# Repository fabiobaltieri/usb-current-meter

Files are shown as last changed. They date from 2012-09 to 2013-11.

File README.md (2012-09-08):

USB Current Meter
=================

This is a set of projects used to monitor the power used in an electrical
system using split core current sensors.

Project page on:

http://fabiobaltieri.com/2012/08/09/usb-current-meter/

License
-------

This program is free software: you can redistribute it and/or modify
it under the terms of the GNU General Public License as published by
the Free Software Foundation, either version 2 of the License, or
(at your option) any later version.

Contents
--------

    COPYING        text version of the GPL
    README         this file
    bootloader-8x/ source directory for 8x version bootloader
    commandline/   source directory for the commandline utility
    firmware*/     source directory for firmware files
    hardware/      source directory for the hardware design files
    rrd/           script and examples for usage with rrdtool

Firmware
--------

Building requires an avr-gcc toolchain, in the firmware/ directory, to build
run:

    make main.hex

Flashing the firmware on the device requires avrdude and a compatible hardware
programmer. Default configuration is stored at the beginning of the Makefile.
To program with the default configuration, run:

    make flash

Fuses can be configured running:

    make fuses

Hardware
--------

All hardware files (schematic, layout and libraries) are in CadSoft Eagle 6
format.

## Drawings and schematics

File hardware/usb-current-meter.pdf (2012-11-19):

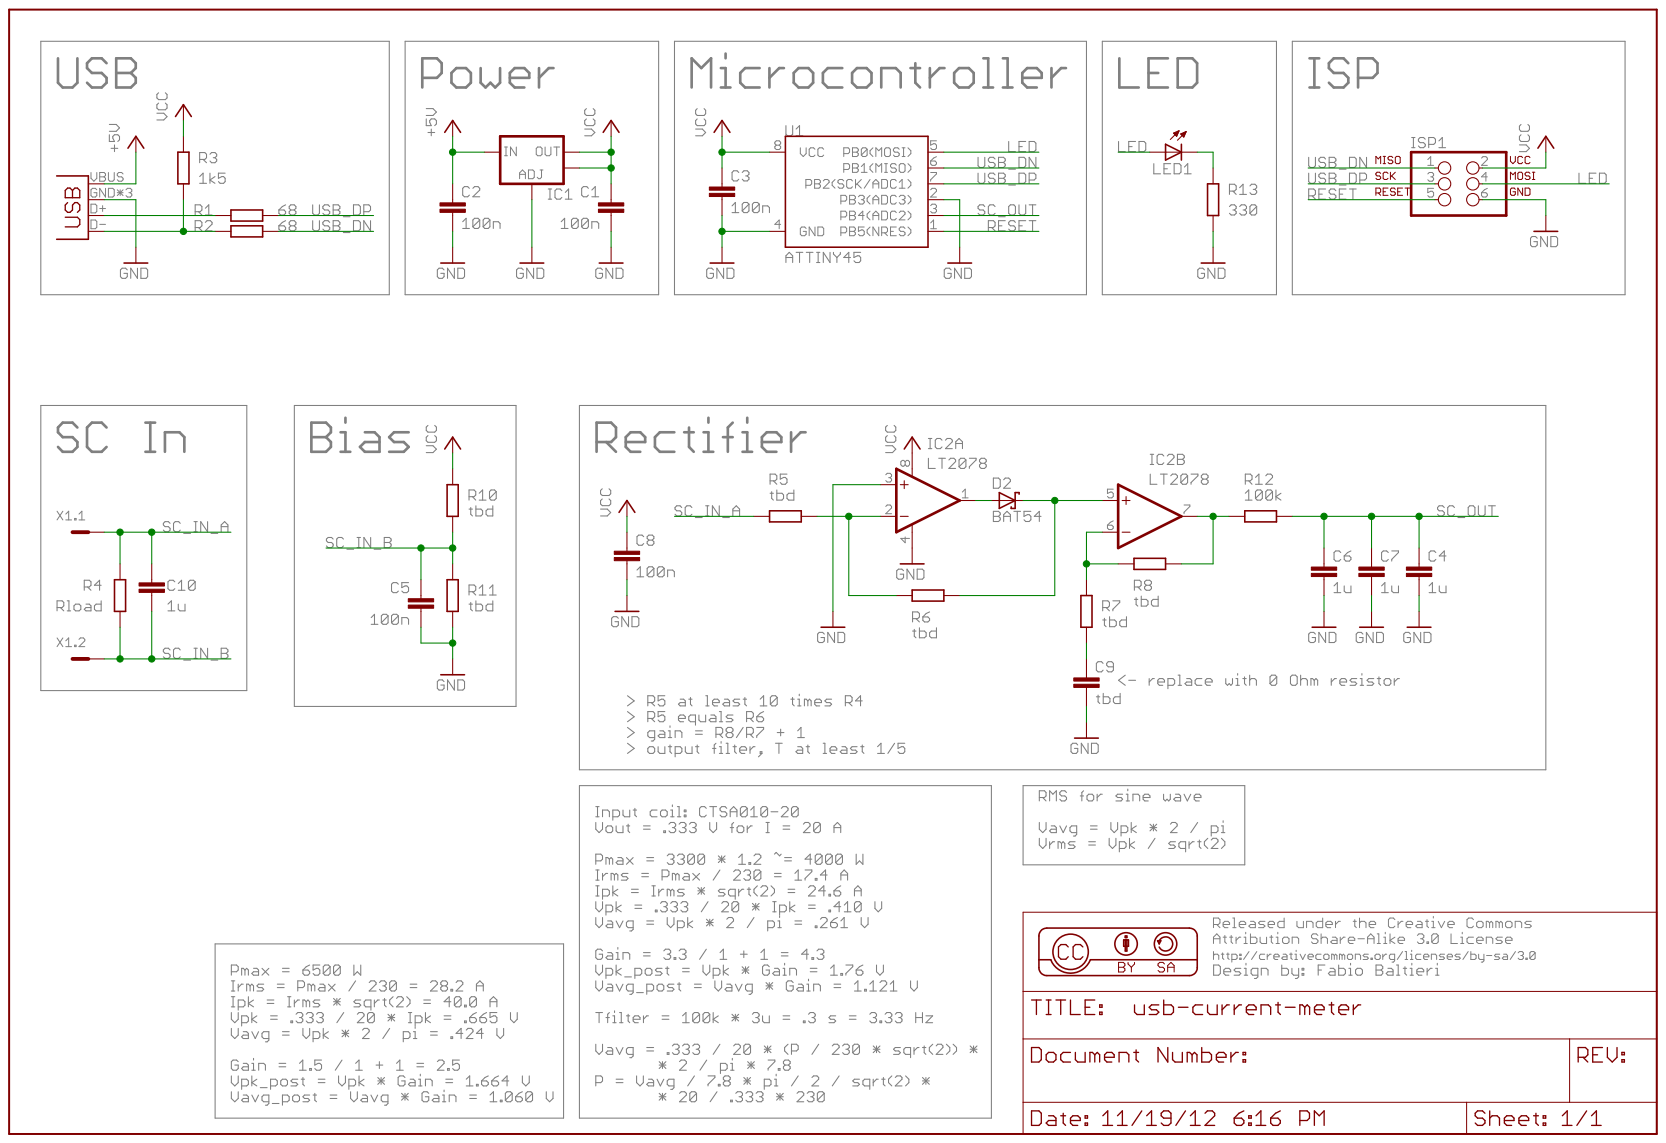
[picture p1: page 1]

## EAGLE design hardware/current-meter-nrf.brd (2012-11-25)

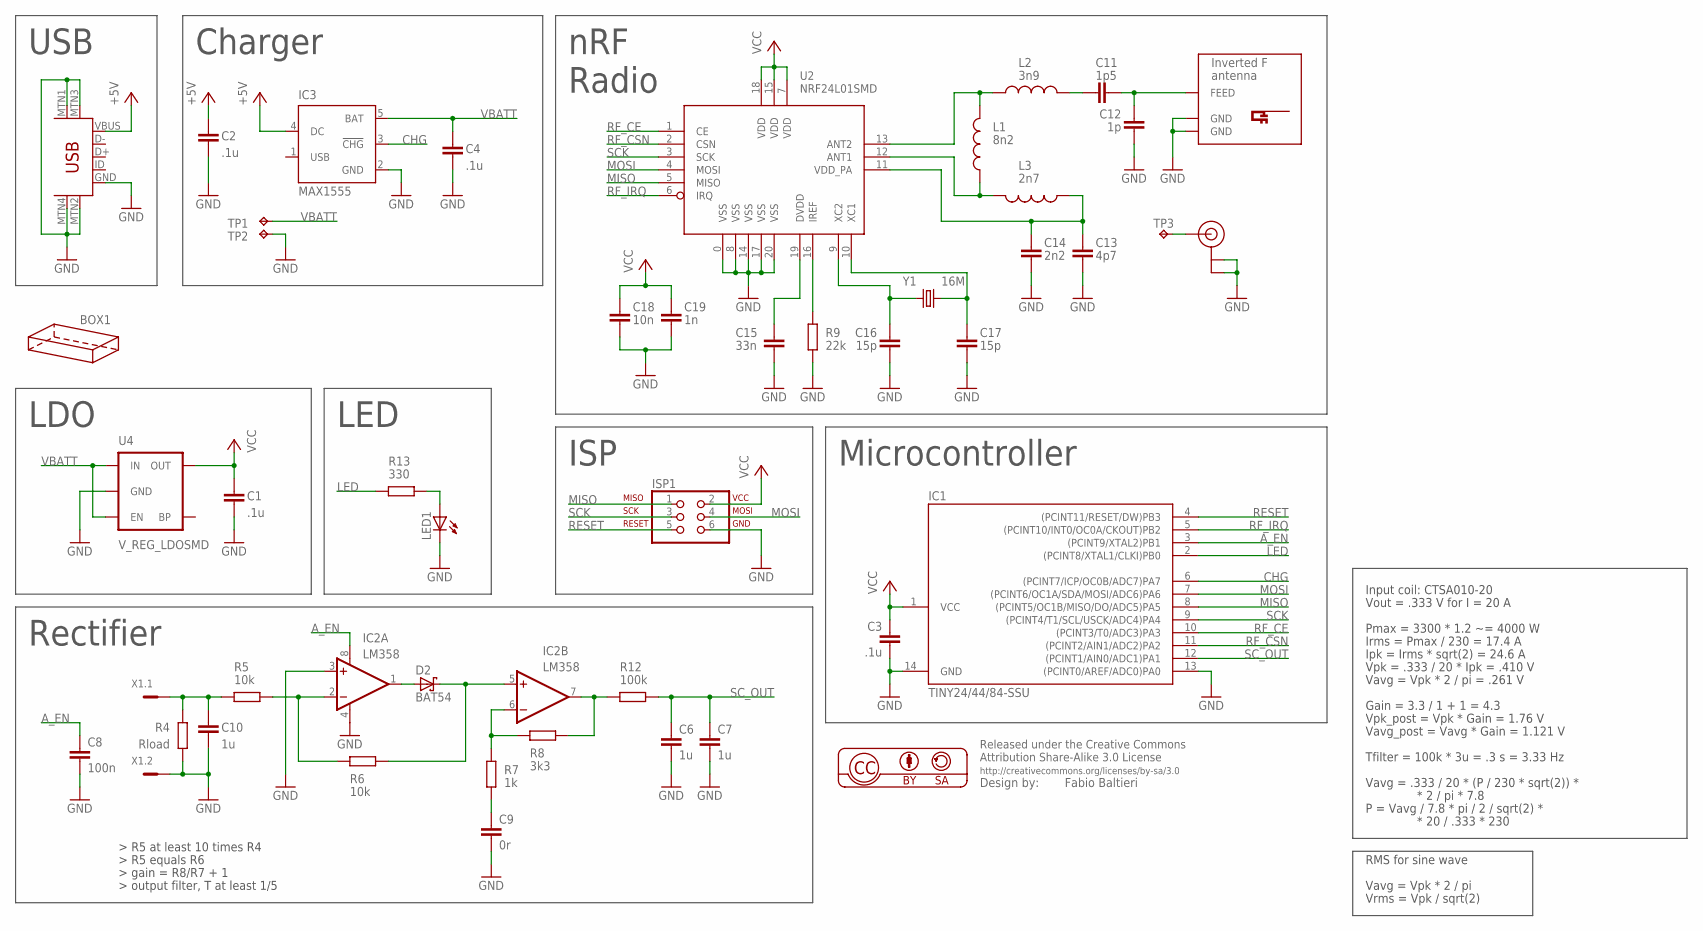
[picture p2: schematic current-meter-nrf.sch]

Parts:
BOX1: HAMMOND-BOX-G-1H; 1551G-1HOLE
C1, C2, C3, C4: .1u; C0805
C6, C7, C10: 1u; C0805
C8: 100n; C0805
C9: 0r; C0805
C11: 1p5; C0603
C12: 1p; C0603
C13: 4p7; C0603
C14: 2n2; C0603
C15: 33n; C0603
C16, C17: 15p; C0603
C18: 10n; C0603
C19: 1n; C0603
D2: BAT54; SOT23
IC1: TINY24/44/84-SSU; SOIC14
IC2: LM358; SO08
IC3: MAX1555; SOT23-5L
ISP1: ISP-AVR910PTH; 2X03
L1: 8n2; 0603
L2: 3n9; 0603
L3: 2n7; 0603
LED1: LEDSML0805; SML0805
R4: Rload; R0805
R5, R6: 10k; R0603
R7: 1k; R0603
R8: 3k3; R0603
R9: 22k; R0603
R12: 100k; R0603
R13: 330; R0603
TP1, TP2: TPTP12R; TP12R
TP3: TPTP08SQ; TP08SQ
U2: NRF24L01SMD; QFN20
U3: USB-MINIB-5PIN; USB-MINIB
U4: V_REG_LDOSMD; SOT23-5
U$1: INVERTED_F_ANTENNA+5; DN007+5
U$2: U.FL
X1: MC2
Y1: 16M; CRYSTAL-SMD-5X3

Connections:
+5V: C2.1, IC3.4 (DC), U3.VBUS
A_EN: C8.1, IC1.3 ((PCINT9/XTAL2)PB1), IC2.8 (V+)
CHG: IC1.6 ((PCINT7/ICP/OC0B/ADC7)PA7), IC3.3 (!CHG)
GND: C1.2, C2.2, C3.2, C4.2, C6.2, C7.2, C8.2, C9.2, C10.2, C12.2, C13.2, C14.2, C15.2, C16.2, C17.2, C18.2, C19.2, IC1.13 ((PCINT0/AREF/ADC0)PA0), IC1.14 (GND), IC2.3 (+IN), IC2.4 (V-), IC3.2 (GND), ISP1.6, LED1.C, R4.1, R9.2, TP2.TP, U2.0 (VSS), U2.8 (VSS), U2.14 (VSS), U2.17 (VSS), U2.20 (VSS), U3.GND, U3.MTN1 (MTN2), U3.MTN2 (MTN3), U3.MTN3 (MTN1), U3.MTN4, U4.2 (GND), U$1.GND, U$1.GND@1 (GND), U$2.P$1 (GND), U$2.P$2 (GND), X1.2
LED: IC1.2 ((PCINT8/XTAL1/CLKI)PB0), R13.2
MISO: IC1.8 ((PCINT5/OC1B/MISO/DO/ADC5)PA5), ISP1.1, U2.5 (MISO)
MOSI: IC1.7 ((PCINT6/OC1A/SDA/MOSI/ADC6)PA6), ISP1.4, U2.4 (MOSI)
unnamed: LED1.A, R13.1
unnamed: C9.1, R7.1
unnamed: L1.2, L3.2, U2.12 (ANT1)
unnamed: L1.1, L2.1, U2.13 (ANT2)
unnamed: IC2.2 (-IN), R5.2, R6.1
unnamed: D2.1 (A), IC2.1 (OUT)
unnamed: D2.3 (C), IC2.5 (+IN), R6.2
unnamed: C11.1, L2.2
unnamed: IC2.6 (-IN), R7.2, R8.1
unnamed: IC2.7 (OUT), R8.2, R12.1
unnamed: C11.2, C12.1, U$1.FEED
unnamed: C13.1, C14.1, L3.1, U2.11 (VDD_PA)
unnamed: C15.1, U2.19 (DVDD)
unnamed: R9.1, U2.16 (IREF)
unnamed: C17.1, U2.10 (XC1), Y1.3 (2)
unnamed: C16.1, U2.9 (XC2), Y1.1
unnamed: TP3.TP, U$2.P$3 (SIGNAL)
RESET: IC1.4 ((PCINT11/RESET/DW)PB3), ISP1.5
RF_CE: IC1.10 ((PCINT3/T0/ADC3)PA3), U2.1 (CE)
RF_CSN: IC1.11 ((PCINT2/AIN1/ADC2)PA2), U2.2 (CSN)
RF_IRQ: IC1.5 ((PCINT10/INT0/OC0A/CKOUT)PB2), U2.6 (IRQ)
SCK: IC1.9 ((PCINT4/T1/SCL/USCK/ADC4)PA4), ISP1.3, U2.3 (SCK)
SC_IN_A: C10.1, R4.2, R5.1, X1.1
SC_OUT: C6.1, C7.1, IC1.12 ((PCINT1/AIN0/ADC1)PA1), R12.2
VBATT: C4.1, IC3.5 (BAT), TP1.TP, U4.1 (IN), U4.3 (EN)
VCC: C1.1, C3.1, C18.1, C19.1, IC1.1 (VCC), ISP1.2, U2.7 (VDD), U2.15 (VDD), U2.18 (VDD), U4.5 (OUT)

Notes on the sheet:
USB
Microcontroller
ISP
LED
Rectifier
Pmax = 3300 * 1.2 ~= 4000 W
Irms = Pmax / 230 = 17.4 A
Ipk = Irms * sqrt(2) = 24.6 A
Vpk = .333 / 20 * Ipk = .410 V
Vout = .333 V for I = 20 A
Input coil: CTSA010-20
Vavg = Vpk * 2 / pi = .261 V
Gain = 3.3 / 1 + 1 = 4.3
Vpk_post = Vpk * Gain = 1.76 V
Vavg_post = Vavg * Gain = 1.121 V
RMS for sine wave
Vavg = Vpk * 2 / pi
Vrms = Vpk / sqrt(2)
Tfilter = 100k * 3u = .3 s = 3.33 Hz
Vavg = .333 / 20 * (P / 230 * sqrt(2)) *
* 2 / pi * 7.8
P = Vavg / 7.8 * pi / 2 / sqrt(2) *
* 20 / .333 * 230
nRF
Charger
Radio
LDO

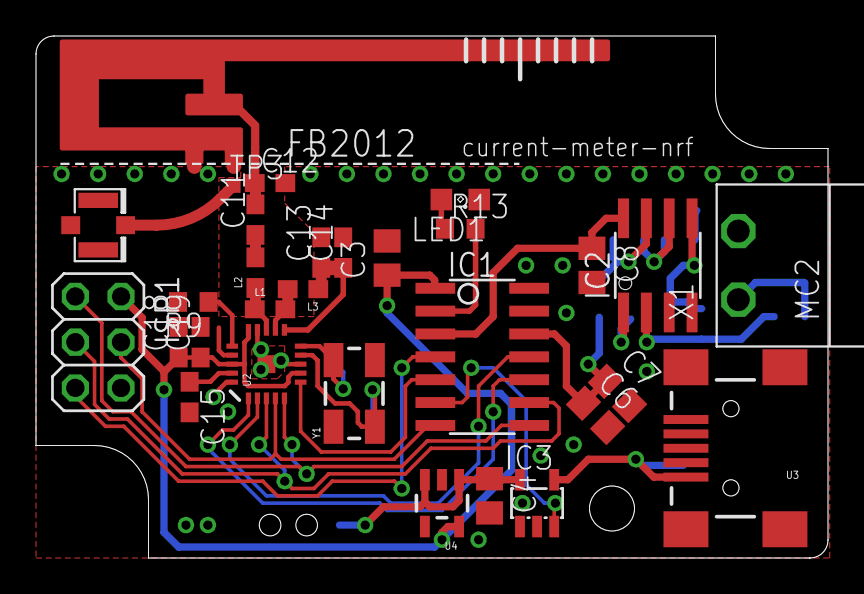
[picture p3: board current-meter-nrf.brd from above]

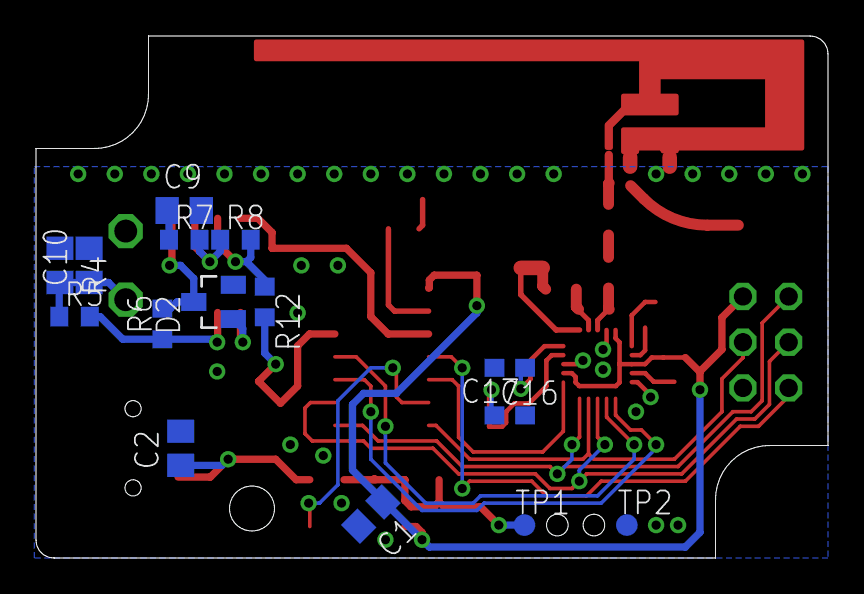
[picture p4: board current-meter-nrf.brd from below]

Board: 2 copper layers, 44.0 x 29.0 mm, 46 parts (15 on the bottom side), 33 nets.

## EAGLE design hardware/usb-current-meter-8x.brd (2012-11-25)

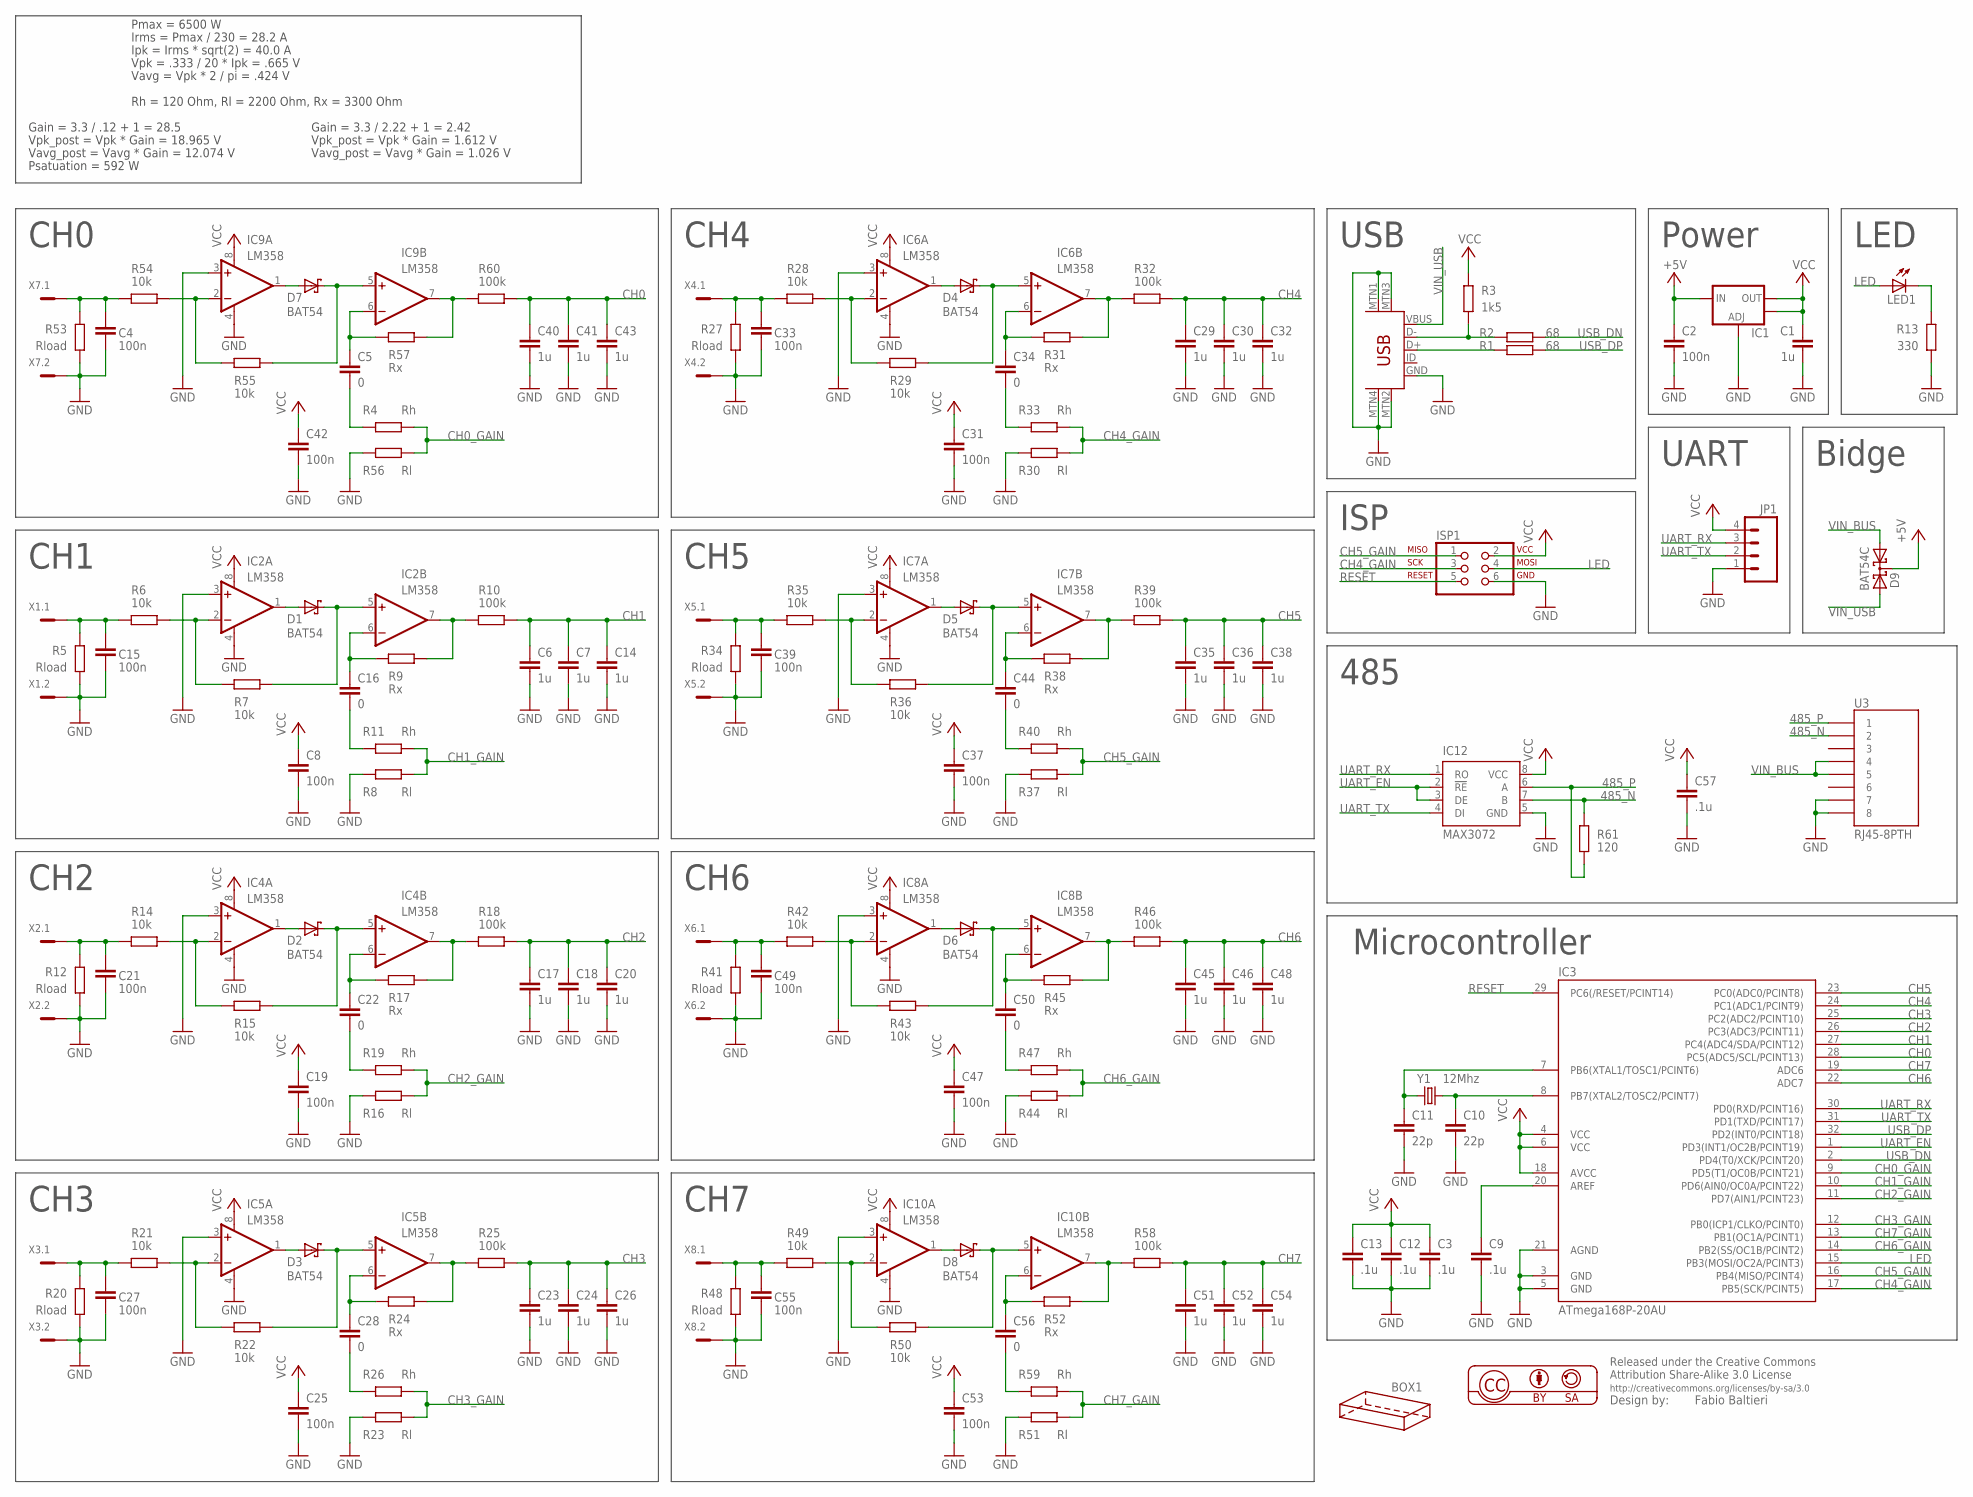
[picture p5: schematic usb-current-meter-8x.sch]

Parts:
BOX1: HAMMOND-BOX-XXA; 1591XXA
C1, C6, C7, C14, C17, C18, C20, C23, C24, C26, C29, C30, C32, C35, C36, C38, C40, C41, C43, C45, C46, C48, C51, C52, C54: 1u; C0805
C2, C4, C8, C15, C19, C21, C25, C27, C31, C33, C37, C39, C42, C47, C49, C53, C55: 100n; C0805
C3, C9, C12, C13, C57: .1u; C0805
C5, C16, C22, C28, C34, C44, C50, C56: 0; C0805
C10, C11: 22p; C0805
D1, D2, D3, D4, D5, D6, D7, D8: BAT54; SOT23
D9: BAT54C; SOT23
IC1: V_REG_LM1117SOT223; SOT223
IC2, IC4, IC5, IC6, IC7, IC8, IC9, IC10: LM358; SO08
IC3: ATmega168P-20AU; TQFP32-08
IC12: MAX3072; SOIC8
ISP1: ISP-AVR910PTH; 2X03
JP1: M04PTH; 1X04
LED1: LEDSML0805; SML0805
R1, R2: 68; R0603
R3: 1k5; R0603
R4, R11, R19, R26, R33, R40, R47, R59: Rh; R0603
R5, R12, R20, R27, R34, R41, R48, R53: Rload; R0805
R6, R7, R14, R15, R21, R22, R28, R29, R35, R36, R42, R43, R49, R50, R54, R55: 10k; R0603
R8, R16, R23, R30, R37, R44, R51, R56: Rl; R0603
R9, R17, R24, R31, R38, R45, R52, R57: Rx; R0603
R10, R18, R25, R32, R39, R46, R58, R60: 100k; R0603
R13: 330; R0603
R61: 120; R0603
U3: RJ45-8PTH; RJ45-8
U$1: USB-MINIB-5PIN; USB-MINIB
U$2: Fabio Baltieri; CREATIVE_COMMONS
X1, X2, X3, X4, X5, X6, X7, X8: MC2
Y1: 12Mhz; HC49U-V

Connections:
485_N: IC12.7 (B), R61.1, U3.2
485_P: IC12.6 (A), R61.2, U3.1
+5V: C2.1, D9.3 (CC), IC1.3 (IN)
CH0: C40.1, C41.1, C43.1, IC3.28 (PC5(ADC5/SCL/PCINT13)), R60.2
CH0_GAIN: IC3.9 (PD5(T1/OC0B/PCINT21)), R4.1, R56.2
CH0_IN: C4.1, R53.2, R54.1, X7.1
CH0_IN1: C15.1, R5.2, R6.1, X1.1
CH0_IN2: C21.1, R12.2, R14.1, X2.1
CH0_IN3: C33.1, R27.2, R28.1, X4.1
CH0_IN4: C39.1, R34.2, R35.1, X5.1
CH0_IN5: C55.1, R48.2, R49.1, X8.1
CH0_IN6: C27.1, R20.2, R21.1, X3.1
CH0_IN8: C49.1, R41.2, R42.1, X6.1
CH1: C6.1, C7.1, C14.1, IC3.27 (PC4(ADC4/SDA/PCINT12)), R10.2
CH1_GAIN: IC3.10 (PD6(AIN0/OC0A/PCINT22)), R8.2, R11.1
CH2: C17.1, C18.1, C20.1, IC3.26 (PC3(ADC3/PCINT11)), R18.2
CH2_GAIN: IC3.11 (PD7(AIN1/PCINT23)), R16.2, R19.1
CH3: C23.1, C24.1, C26.1, IC3.25 (PC2(ADC2/PCINT10)), R25.2
CH3_GAIN: IC3.12 (PB0(ICP1/CLKO/PCINT0)), R23.2, R26.1
CH4: C29.1, C30.1, C32.1, IC3.24 (PC1(ADC1/PCINT9)), R32.2
CH4_GAIN: IC3.17 (PB5(SCK/PCINT5)), ISP1.3, R30.2, R33.1
CH5: C35.1, C36.1, C38.1, IC3.23 (PC0(ADC0/PCINT8)), R39.2
CH5_GAIN: IC3.16 (PB4(MISO/PCINT4)), ISP1.1, R37.2, R40.1
CH6: C45.1, C46.1, C48.1, IC3.22 (ADC7), R46.2
CH6_GAIN: IC3.14 (PB2(SS/OC1B/PCINT2)), R44.2, R47.1
CH7: C51.1, C52.1, C54.1, IC3.19 (ADC6), R58.2
CH7_GAIN: IC3.13 (PB1(OC1A/PCINT1)), R51.2, R59.1
GND: C1.2, C2.2, C3.2, C4.2, C6.2, C7.2, C8.2, C9.2, C10.2, C11.2, C12.2, C13.2, C14.2, C15.2, C17.2, C18.2, C19.2, C20.2, C21.2, C23.2, C24.2, C25.2, C26.2, C27.2, C29.2, C30.2, C31.2, C32.2, C33.2, C35.2, C36.2, C37.2, C38.2, C39.2, C40.2, C41.2, C42.2, C43.2, C45.2, C46.2, C47.2, C48.2, C49.2, C51.2, C52.2, C53.2, C54.2, C55.2, C57.2, IC1.1 (ADJ), IC2.3 (+IN), IC2.4 (V-), IC3.3 (GND), IC3.5 (GND), IC3.21 (AGND), IC4.3 (+IN), IC4.4 (V-), IC5.3 (+IN), IC5.4 (V-), IC6.3 (+IN), IC6.4 (V-), IC7.3 (+IN), IC7.4 (V-), IC8.3 (+IN), IC8.4 (V-), IC9.3 (+IN), IC9.4 (V-), IC10.3 (+IN), IC10.4 (V-), IC12.5 (GND), ISP1.6, JP1.1, R5.1, R8.1, R12.1, R13.1, R16.1, R20.1, R23.1, R27.1, R30.1, R34.1, R37.1, R41.1, R44.1, R48.1, R51.1, R53.1, R56.1, U3.7, U3.8, U$1.GND, U$1.MTN1 (MTN2), U$1.MTN2 (MTN3), U$1.MTN3 (MTN1), U$1.MTN4, X1.2, X2.2, X3.2, X4.2, X5.2, X6.2, X7.2, X8.2
LED: IC3.15 (PB3(MOSI/OC2A/PCINT3)), ISP1.4, LED1.A
unnamed: R2.1, R3.1, U$1.D-
unnamed: R1.1, U$1.D+
unnamed: LED1.C, R13.2
unnamed: C11.1, IC3.7 (PB6(XTAL1/TOSC1/PCINT6)), Y1.1
unnamed: C10.1, IC3.8 (PB7(XTAL2/TOSC2/PCINT7)), Y1.2
unnamed: C9.1, IC3.20 (AREF)
unnamed: C5.2, R4.2
unnamed: IC2.2 (-IN), R6.2, R7.1
unnamed: D1.1 (A), IC2.1 (OUT)
unnamed: D1.3 (C), IC2.5 (+IN), R7.2
unnamed: C16.1, IC2.6 (-IN), R9.1
unnamed: IC2.7 (OUT), R9.2, R10.1
unnamed: C16.2, R11.2
unnamed: IC4.2 (-IN), R14.2, R15.1
unnamed: D2.1 (A), IC4.1 (OUT)
unnamed: D2.3 (C), IC4.5 (+IN), R15.2
unnamed: C22.1, IC4.6 (-IN), R17.1
unnamed: IC4.7 (OUT), R17.2, R18.1
unnamed: C22.2, R19.2
unnamed: IC6.2 (-IN), R28.2, R29.1
unnamed: D4.1 (A), IC6.1 (OUT)
unnamed: D4.3 (C), IC6.5 (+IN), R29.2
unnamed: C34.1, IC6.6 (-IN), R31.1
unnamed: IC6.7 (OUT), R31.2, R32.1
unnamed: C34.2, R33.2
unnamed: IC7.2 (-IN), R35.2, R36.1
unnamed: D5.1 (A), IC7.1 (OUT)
unnamed: D5.3 (C), IC7.5 (+IN), R36.2
unnamed: C44.1, IC7.6 (-IN), R38.1
unnamed: IC7.7 (OUT), R38.2, R39.1
unnamed: C44.2, R40.2
unnamed: IC10.2 (-IN), R49.2, R50.1
unnamed: D8.1 (A), IC10.1 (OUT)
unnamed: D8.3 (C), IC10.5 (+IN), R50.2
unnamed: C56.1, IC10.6 (-IN), R52.1
unnamed: IC10.7 (OUT), R52.2, R58.1
unnamed: IC9.2 (-IN), R54.2, R55.1
unnamed: D7.1 (A), IC9.1 (OUT)
unnamed: D7.3 (C), IC9.5 (+IN), R55.2
unnamed: C5.1, IC9.6 (-IN), R57.1
unnamed: IC9.7 (OUT), R57.2, R60.1
unnamed: C56.2, R59.2
unnamed: IC5.2 (-IN), R21.2, R22.1
unnamed: D3.1 (A), IC5.1 (OUT)
unnamed: D3.3 (C), IC5.5 (+IN), R22.2
unnamed: C28.1, IC5.6 (-IN), R24.1
unnamed: IC5.7 (OUT), R24.2, R25.1
unnamed: C28.2, R26.2
unnamed: IC8.2 (-IN), R42.2, R43.1
unnamed: D6.1 (A), IC8.1 (OUT)
unnamed: D6.3 (C), IC8.5 (+IN), R43.2
unnamed: C50.1, IC8.6 (-IN), R45.1
unnamed: IC8.7 (OUT), R45.2, R46.1
unnamed: C50.2, R47.2
RESET: IC3.29 (PC6(/RESET/PCINT14)), ISP1.5
UART_EN: IC3.1 (PD3(INT1/OC2B/PCINT19)), IC12.2 (!RE), IC12.3 (DE)
UART_RX: IC3.30 (PD0(RXD/PCINT16)), IC12.1 (RO), JP1.3
UART_TX: IC3.31 (PD1(TXD/PCINT17)), IC12.4 (DI), JP1.2
USB_DN: IC3.2 (PD4(T0/XCK/PCINT20)), R2.2
USB_DP: IC3.32 (PD2(INT0/PCINT18)), R1.2
VCC: C1.1, C3.1, C8.1, C12.1, C13.1, C19.1, C25.1, C31.1, C37.1, C42.1, C47.1, C53.1, C57.1, IC1.2 (OUT), IC1.4 (OUT), IC2.8 (V+), IC3.4 (VCC), IC3.6 (VCC), IC3.18 (AVCC), IC4.8 (V+), IC5.8 (V+), IC6.8 (V+), IC7.8 (V+), IC8.8 (V+), IC9.8 (V+), IC10.8 (V+), IC12.8 (VCC), ISP1.2, JP1.4, R3.2
VIN_BUS: D9.1 (A1), U3.4, U3.5
VIN_USB: D9.2 (A2), U$1.VBUS

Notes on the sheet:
USB
Power
Microcontroller
ISP
LED
CH0
UART
CH1
CH2
CH3
CH4
CH5
CH6
CH7
485
Bidge
Pmax = 6500 W
Irms = Pmax / 230 = 28.2 A
Ipk = Irms * sqrt(2) = 40.0 A
Vpk = .333 / 20 * Ipk = .665 V
Vavg = Vpk * 2 / pi = .424 V
Gain = 3.3 / .12 + 1 = 28.5
Vpk_post = Vpk * Gain = 18.965 V
Vavg_post = Vavg * Gain = 12.074 V
Rh = 120 Ohm, Rl = 2200 Ohm, Rx = 3300 Ohm
Gain = 3.3 / 2.22 + 1 = 2.42
Vpk_post = Vpk * Gain = 1.612 V
Vavg_post = Vavg * Gain = 1.026 V
Psatuation = 592 W

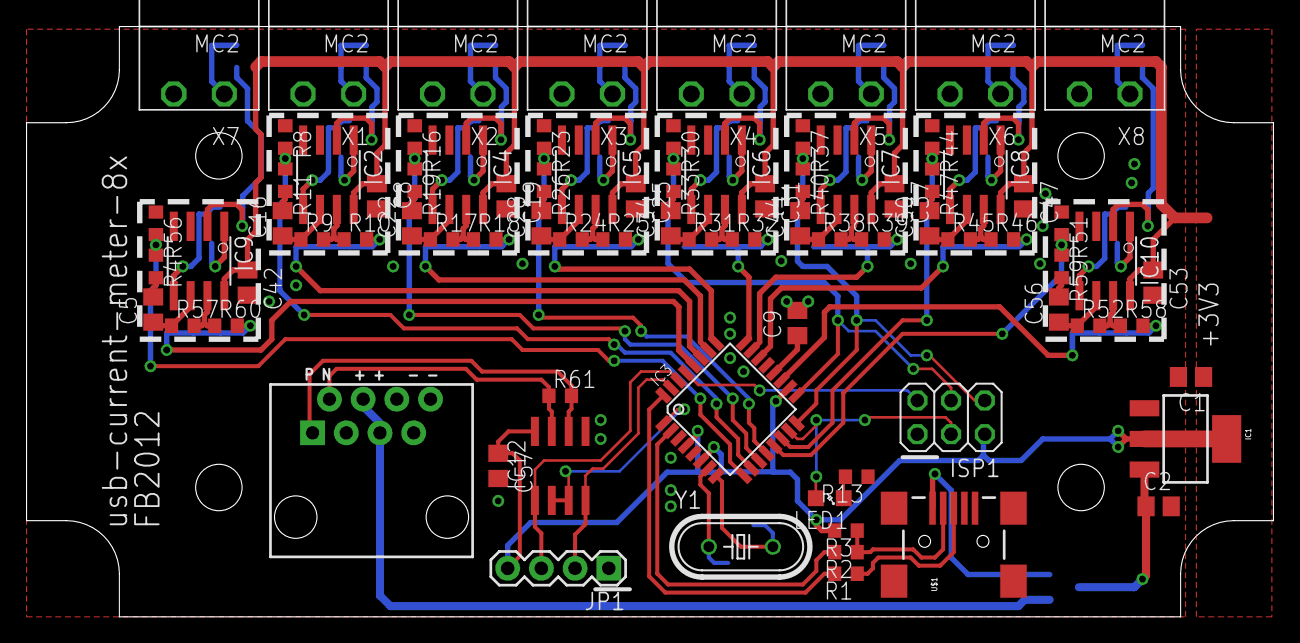
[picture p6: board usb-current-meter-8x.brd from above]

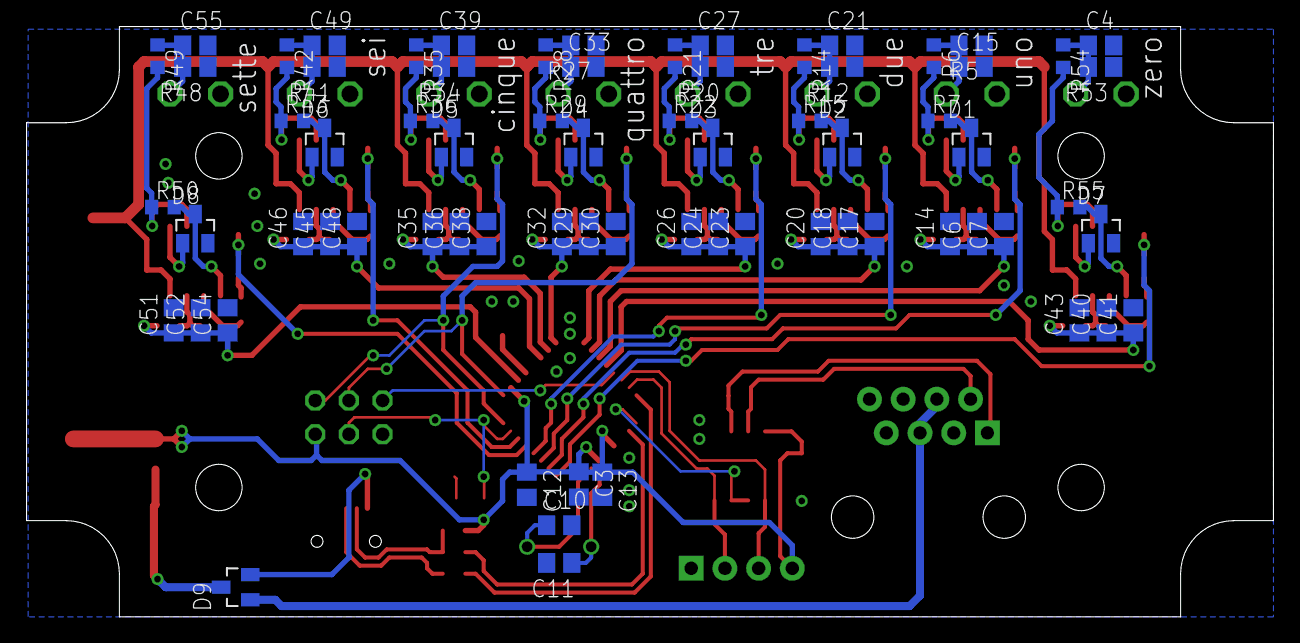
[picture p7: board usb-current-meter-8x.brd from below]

Board: 2 copper layers, 94.0 x 44.5 mm, 154 parts (70 on the bottom side), 92 nets.

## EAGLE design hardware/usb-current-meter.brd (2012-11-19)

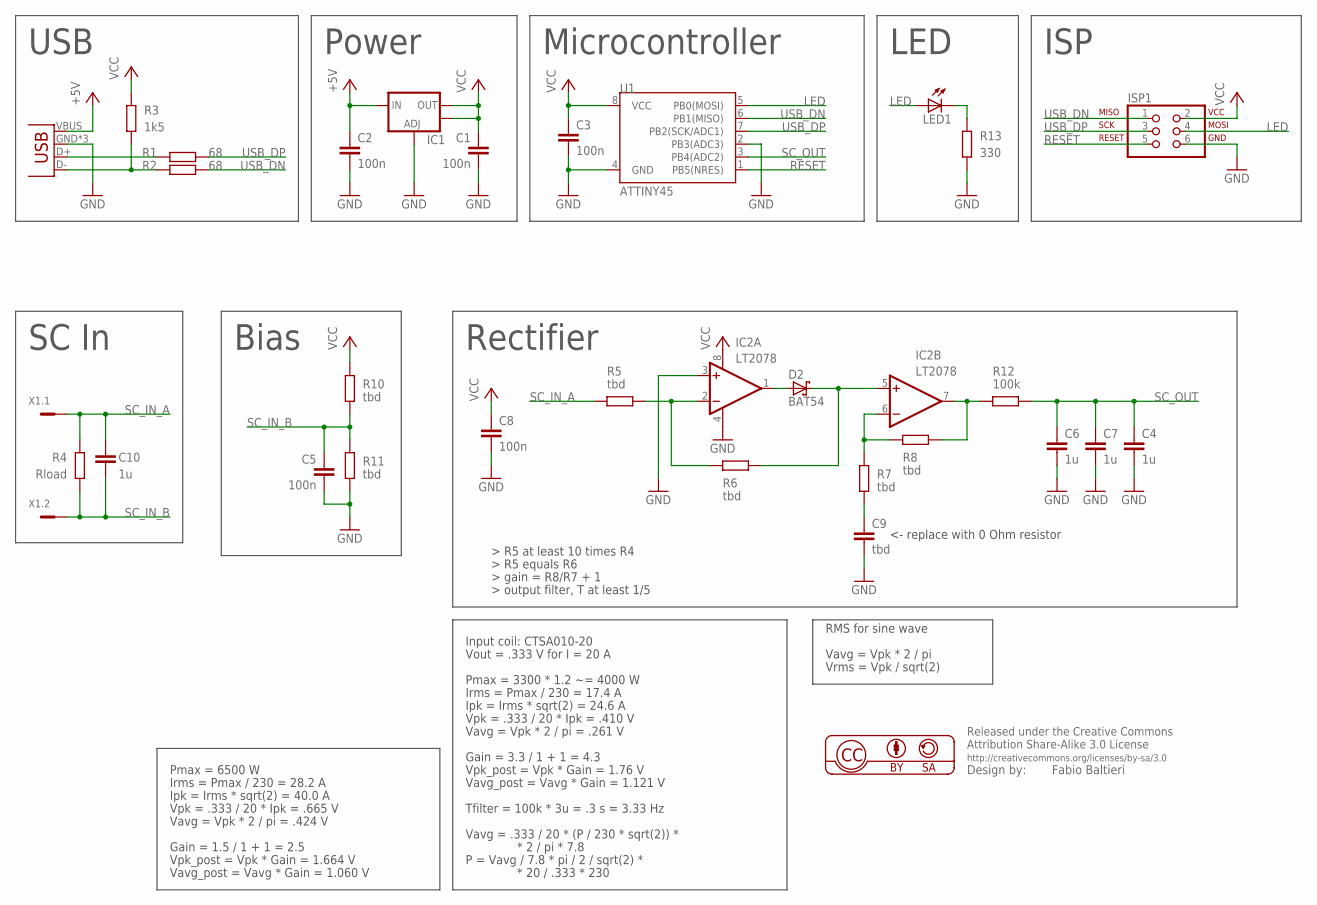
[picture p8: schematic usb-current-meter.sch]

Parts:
C1, C2, C3, C5, C8: 100n; C0805
C4, C6, C7, C10: 1u; C0805
C9: tbd; C0805
D2: BAT54; SOT23
IC1: V_REG_LM1117SOT223; SOT223
IC2: LT2078; SO08
ISP1: ISP-AVR910; 2X03_BORDER_TP
LED1: LEDSML0805; SML0805
R1, R2: 68; R0603
R3: 1k5; R0603
R4: Rload; R0805
R5, R6, R7, R8, R10, R11: tbd; R0603
R12: 100k; R0603
R13: 330; R0603
U1: ATTINY45; SO08-EIAJ
X1: MC2
X3: USB-A-H

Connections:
+5V: C2.1, IC1.3 (IN), X3.VBUS (GND)
GND: C1.2, C2.2, C3.2, C4.2, C5.2, C6.2, C7.2, C8.2, C9.2, IC1.1 (ADJ), IC2.3 (+IN), IC2.4 (V-), ISP1.6, R11.1, R13.1, U1.2 (PB3(ADC3)), U1.4 (GND), X3.GND (VBUS), X3.GND2 (VBUS), X3.GND3 (VBUS)
LED: ISP1.4, LED1.A, U1.5 (PB0(MOSI))
unnamed: R2.1, R3.1, X3.D- (D+)
unnamed: R1.1, X3.D+ (D-)
unnamed: LED1.C, R13.2
unnamed: C9.1, R7.1
unnamed: IC2.2 (-IN), R5.2, R6.1
unnamed: D2.1 (A), IC2.1 (OUT)
unnamed: D2.3 (C), IC2.5 (+IN), R6.2
unnamed: IC2.6 (-IN), R7.2, R8.1
unnamed: IC2.7 (OUT), R8.2, R12.1
RESET: ISP1.5, U1.1 (PB5(NRES))
SC_IN_A: C10.1, R4.2, R5.1, X1.1
SC_IN_B: C5.1, C10.2, R4.1, R10.1, R11.2, X1.2
SC_OUT: C4.1, C6.1, C7.1, R12.2, U1.3 (PB4(ADC2))
USB_DN: ISP1.1, R2.2, U1.6 (PB1(MISO))
USB_DP: ISP1.3, R1.2, U1.7 (PB2(SCK/ADC1))
VCC: C1.1, C3.1, C8.1, IC1.2 (OUT), IC1.4 (OUT), IC2.8 (V+), ISP1.2, R3.2, R10.2, U1.8 (VCC)

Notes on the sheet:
USB
Power
Microcontroller
ISP
LED
SC In
Rectifier
Bias
Pmax = 3300 * 1.2 ~= 4000 W
Irms = Pmax / 230 = 17.4 A
Ipk = Irms * sqrt(2) = 24.6 A
Vpk = .333 / 20 * Ipk = .410 V
Vout = .333 V for I = 20 A
Input coil: CTSA010-20
Vavg = Vpk * 2 / pi = .261 V
Gain = 3.3 / 1 + 1 = 4.3
Vpk_post = Vpk * Gain = 1.76 V
Vavg_post = Vavg * Gain = 1.121 V
RMS for sine wave
Vavg = Vpk * 2 / pi
Vrms = Vpk / sqrt(2)
Tfilter = 100k * 3u = .3 s = 3.33 Hz
Vavg = .333 / 20 * (P / 230 * sqrt(2)) *
* 2 / pi * 7.8
P = Vavg / 7.8 * pi / 2 / sqrt(2) *
* 20 / .333 * 230
Pmax = 6500 W
Irms = Pmax / 230 = 28.2 A
Ipk = Irms * sqrt(2) = 40.0 A
Vpk = .333 / 20 * Ipk = .665 V
Vavg = Vpk * 2 / pi = .424 V
Gain = 1.5 / 1 + 1 = 2.5
Vpk_post = Vpk * Gain = 1.664 V
Vavg_post = Vavg * Gain = 1.060 V
<- replace with 0 Ohm resistor

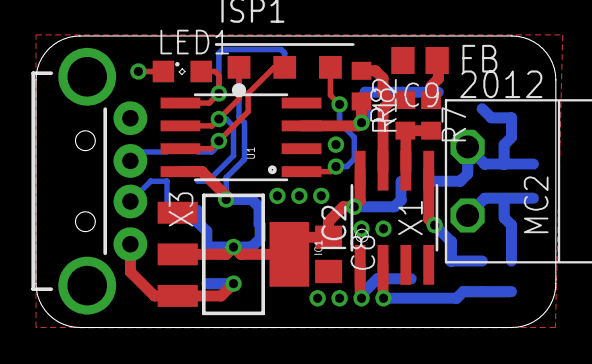
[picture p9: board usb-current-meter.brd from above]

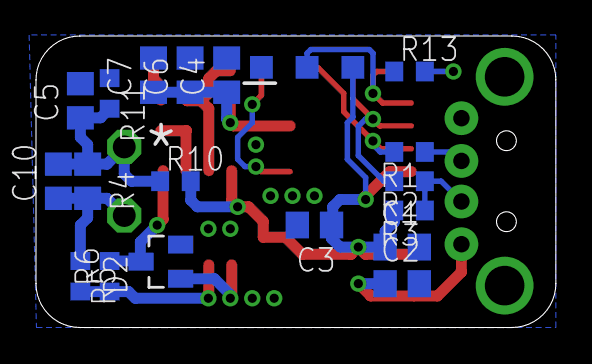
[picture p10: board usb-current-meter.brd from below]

Board: 2 copper layers, 28.9 x 16.2 mm, 30 parts (18 on the bottom side), 19 nets.

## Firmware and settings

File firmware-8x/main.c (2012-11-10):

#include "board.h"

#include <avr/io.h>
#include <avr/wdt.h>
#include <avr/interrupt.h>
#include <util/delay.h>
#include <string.h>

#include "usbdrv.h"

#include "requests.h"
#include "adc.h"

#define NR_CHANNELS 8

static uint8_t current_channel;

static uint16_t buffer_values[NR_CHANNELS];
static uint32_t instant_values[NR_CHANNELS];
static uint8_t gain_mask;

static struct host_frame {
	uint16_t host_values[NR_CHANNELS];
	uint16_t sample_count;
	uint8_t gain_mask;
} hf;

static uint16_t buffer_counter;

static const uint8_t map[NR_CHANNELS] = {
	5, 4, 3, 2, 1, 0, 7, 6
};

static uint16_t blink_counter = 0;

static void reset_cpu(void)
{
	wdt_disable();

	wdt_enable(WDTO_15MS);

	for (;;);
}

#define is_high_gain(mask, ch) (mask & (1 << ch))

#define div_round(a, b) (((a) + ((b)/2)) / (b))
static uint16_t get_power(void)
{
	uint32_t value;

	value  = adc_get_value();

	if (is_high_gain(gain_mask, current_channel))
		value = div_round(value * ADC_VREF_mV * CAL_POWER,
				ADC_VREF_BITS * CAL_VOLTAGE_H);
	else
		value = div_round(value * ADC_VREF_mV * CAL_POWER,
				ADC_VREF_BITS * CAL_VOLTAGE_L);

	return value;
}

static void set_high_gain(uint8_t channel)
{
	switch (channel) {
		case 0:
			set_high_gain_ch0();
			break;
		case 1:
			set_high_gain_ch1();
			break;
		case 2:
			set_high_gain_ch2();
			break;
		case 3:
			set_high_gain_ch3();
			break;
		case 4:
			set_high_gain_ch4();
			break;
		case 5:
			set_high_gain_ch5();
			break;
		case 6:
			set_high_gain_ch6();
			break;
		case 7:
			set_high_gain_ch7();
			break;
	}

	gain_mask |= (1 << channel);
}

static void set_low_gain(uint8_t channel)
{
	switch (channel) {
		case 0:
			set_low_gain_ch0();
			break;
		case 1:
			set_low_gain_ch1();
			break;
		case 2:
			set_low_gain_ch2();
			break;
		case 3:
			set_low_gain_ch3();
			break;
		case 4:
			set_low_gain_ch4();
			break;
		case 5:
			set_low_gain_ch5();
			break;
		case 6:
			set_low_gain_ch6();
			break;
		case 7:
			set_low_gain_ch7();
			break;
	}

	gain_mask &= ~(1 << channel);
}

static void change_channel_gain(uint8_t channel)
{
#if 0
	if (!is_high_gain(gain_mask, channel) &&
			buffer_values[channel] < AMP_TH_L) {
		set_high_gain(channel);
	} else if (is_high_gain(gain_mask, channel) &&
			buffer_values[channel] > AMP_TH_H) {
		set_low_gain(channel);
	}
#else
	set_low_gain(channel);
#endif

	adc_set_channel(map[channel]);
}

static void buffer_poll(void)
{
	uint8_t i;

	if (!(TIFR0 & _BV(OCIE0A)))
		return;

	buffer_values[current_channel] = get_power();

	current_channel = (current_channel + 1) % NR_CHANNELS;
	change_channel_gain(current_channel);

	if (current_channel == 0) {
		buffer_counter++;

		/* overflow, start from 1 */
		if (buffer_counter == UINT16_MAX) {
			buffer_counter = 1;
			memset(instant_values, 0,
					sizeof(instant_values));
		}

		for (i = 0; i < NR_CHANNELS; i++)
			instant_values[i] += buffer_values[i];
	}

	TIFR0 |= _BV(OCIE0A);
}

static void buffer_get(void)
{
	uint8_t i;

	/* return last values if no new dataset */
	if (buffer_counter == 0)
		return;

	for (i = 0; i < NR_CHANNELS; i++)
		hf.host_values[i] = instant_values[i] / buffer_counter;

	hf.sample_count = buffer_counter;
	hf.gain_mask = gain_mask;

	buffer_counter = 0;
	memset(instant_values, 0, sizeof(instant_values));
}

static void timer_setup(void)
{
	OCR0A = F_CPU / 1024 / 100; /* about 100 Hz */

	TIFR0 |= _BV(OCIE0A);

	TCCR0A = ( (1 << WGM01) | (0 << WGM00) );
	TCCR0B = ( (0 << WGM02) |
			(1 << CS02) | (0 << CS01) | (1 << CS00) );
}

static void blink(void)
{
	led_a_off();
	blink_counter = 15000;
}

static void blink_poll(void)
{
	if (blink_counter)
		blink_counter--;
	else
		led_a_on();
}

usbMsgLen_t usbFunctionSetup(uint8_t data[8])
{
	struct usbRequest *rq = (void *)data;

	switch (rq->bRequest) {
	case CUSTOM_RQ_GET_VALUES:
		blink();
		buffer_get();
		usbMsgPtr = (uint8_t *)&hf;
		return sizeof(hf);
	case CUSTOM_RQ_RESET:
		reset_cpu();
		return 0;
	}

	return 0;
}

void hello(void)
{
	uint8_t i;
	for (i = 0; i < 9; i++) {
		led_a_toggle();
		_delay_ms(33);
	}
}

int __attribute__((noreturn)) main(void)
{
	uint8_t i;

	led_init();
	led_a_off();

	adc_init();
	DIDR0 |= _BV(ADC5D) | _BV(ADC4D) |
		 _BV(ADC3D) | _BV(ADC2D) |
		 _BV(ADC1D) | _BV(ADC0D);

	set_low_gain_ch0();
	set_low_gain_ch1();
	set_low_gain_ch2();
	set_low_gain_ch3();
	set_low_gain_ch4();
	set_low_gain_ch5();
	set_low_gain_ch6();
	set_low_gain_ch7();

	wdt_enable(WDTO_1S);

	hello();

	usbInit();
	usbDeviceDisconnect();

	i = 0;
	while (--i) {
		wdt_reset();
		_delay_ms(1);
	}

	usbDeviceConnect();

	/* clear data */
	current_channel = 0;
	gain_mask = 0;
	memset(buffer_values, 0, sizeof(buffer_values));
	memset(instant_values, 0, sizeof(instant_values));
	memset(&hf, 0, sizeof(hf));

	timer_setup();

	sei();
	for (;;) {
		wdt_reset();
		usbPoll();
		buffer_poll();
		blink_poll();
	}
}

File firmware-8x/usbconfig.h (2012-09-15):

/* Name: usbconfig.h
 * Project: V-USB, virtual USB port for Atmel's(r) AVR(r) microcontrollers
 * Author: Christian Starkjohann
 * Creation Date: 2005-04-01
 * Tabsize: 4
 * Copyright: (c) 2005 by OBJECTIVE DEVELOPMENT Software GmbH
 * License: GNU GPL v2 (see License.txt), GNU GPL v3 or proprietary (CommercialLicense.txt)
 * This Revision: $Id$
 */

#ifndef __usbconfig_h_included__
#define __usbconfig_h_included__

/*
General Description:
This file is an example configuration (with inline documentation) for the USB
driver. It configures V-USB for USB D+ connected to Port D bit 2 (which is
also hardware interrupt 0 on many devices) and USB D- to Port D bit 4. You may
wire the lines to any other port, as long as D+ is also wired to INT0 (or any
other hardware interrupt, as long as it is the highest level interrupt, see
section at the end of this file).
+ To create your own usbconfig.h file, copy this file to your project's
+ firmware source directory) and rename it to "usbconfig.h".
+ Then edit it accordingly.
*/

/* ---------------------------- Hardware Config ---------------------------- */

#define USB_CFG_IOPORTNAME      D
/* This is the port where the USB bus is connected. When you configure it to
 * "B", the registers PORTB, PINB and DDRB will be used.
 */
#define USB_CFG_DMINUS_BIT      4
/* This is the bit number in USB_CFG_IOPORT where the USB D- line is connected.
 * This may be any bit in the port.
 */
#define USB_CFG_DPLUS_BIT       2
/* This is the bit number in USB_CFG_IOPORT where the USB D+ line is connected.
 * This may be any bit in the port. Please note that D+ must also be connected
 * to interrupt pin INT0! [You can also use other interrupts, see section
 * "Optional MCU Description" below, or you can connect D- to the interrupt, as
 * it is required if you use the USB_COUNT_SOF feature. If you use D- for the
 * interrupt, the USB interrupt will also be triggered at Start-Of-Frame
 * markers every millisecond.]
 */
#define USB_CFG_CLOCK_KHZ       (F_CPU/1000)
/* Clock rate of the AVR in kHz. Legal values are 12000, 12800, 15000, 16000,
 * 16500, 18000 and 20000. The 12.8 MHz and 16.5 MHz versions of the code
 * require no crystal, they tolerate +/- 1% deviation from the nominal
 * frequency. All other rates require a precision of 2000 ppm and thus a
 * crystal!
 * Since F_CPU should be defined to your actual clock rate anyway, you should
 * not need to modify this setting.
 */
#define USB_CFG_CHECK_CRC       0
/* Define this to 1 if you want that the driver checks integrity of incoming
 * data packets (CRC checks). CRC checks cost quite a bit of code size and are
 * currently only available for 18 MHz crystal clock. You must choose
 * USB_CFG_CLOCK_KHZ = 18000 if you enable this option.
 */

/* ----------------------- Optional Hardware Config ------------------------ */

/* #define USB_CFG_PULLUP_IOPORTNAME   D */
/* If you connect the 1.5k pullup resistor from D- to a port pin instead of
 * V+, you can connect and disconnect the device from firmware by calling
 * the macros usbDeviceConnect() and usbDeviceDisconnect() (see usbdrv.h).
 * This constant defines the port on which the pullup resistor is connected.
 */
/* #define USB_CFG_PULLUP_BIT          4 */
/* This constant defines the bit number in USB_CFG_PULLUP_IOPORT (defined
 * above) where the 1.5k pullup resistor is connected. See description
 * above for details.
 */

/* --------------------------- Functional Range ---------------------------- */
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

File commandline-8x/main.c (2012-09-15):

#include <stdio.h>
#include <stdlib.h>
#include <string.h>
#include <stdint.h>
#include <unistd.h>
#include <fcntl.h>
#include <sys/stat.h>
#include <sys/types.h>
#include <endian.h>

#include <usb.h>

#include "opendevice.h"

#include "../firmware-8x/requests.h"

#define NR_CHANNELS 8

static struct host_frame {
	uint16_t host_values[NR_CHANNELS];
	uint16_t sample_count;
	uint8_t gain_mask;
} hf;

#define PRODUCT "usb-current-meter-8x"

#define NOMINAL_VOLTAGE 230

static int get_power(usb_dev_handle *handle)
{
	int ret;

	ret = usb_control_msg(handle,
			      USB_TYPE_VENDOR | USB_RECIP_DEVICE |
			      USB_ENDPOINT_IN,
			      CUSTOM_RQ_GET_VALUES,
			      0, 0, (char *)&hf, sizeof(hf), 1000);

	if (ret < 0) {
		printf("usb_control_msg: %s\n", usb_strerror());
		exit(1);
	}

	//data = le16toh(data);

	return ret;
}

static void send_reset(usb_dev_handle *handle)
{
	int ret;

	ret = usb_control_msg(handle,
			      USB_TYPE_VENDOR | USB_RECIP_DEVICE |
			      USB_ENDPOINT_IN,
			      CUSTOM_RQ_RESET,
			      0, 0, NULL, 0, 1000);

	if (ret < 0) {
		printf("usb_control_msg: %s\n", usb_strerror());
		exit(1);
	}
}

static void usage(char *name)
{
	fprintf(stderr, "Usage: %s -h\n", name);
	fprintf(stderr, "       %s -R\n", name);
	fprintf(stderr, "       %s [options] divisor\n", name);
	fprintf(stderr, "options:\n"
			"  -h         this help\n"
			"  -R         reset device\n"
			"  -b         run in background\n"
			"  -d delay   delay between updates\n"
			"  -r dbname  rrdtool update mode on dbname db\n"
			"  -V voltage scale output for real voltage instead of nominal\n"
			"  divisor    power divisor, correspond to number of turns on the sensor\n"
			);
	exit(1);
}

static void daemonize(void)
{
	int i;
	pid_t pid;

	if ((i = open("/dev/null", O_RDONLY)) != 0) {
		dup2(i, 0);
		close(i);
	}
	if ((i = open("/dev/null", O_WRONLY)) != 1) {
		dup2(i, 1);
		close(i);
	}
	if ((i = open("/dev/null", O_WRONLY)) != 2) {
		dup2(i, 2);
		close(i);
	}

	setsid();

	pid = fork();

	if (pid < 0) {
		perror("fork");
		exit(1);
	} else if (pid) { /* parent */
		exit(0);
	} else { /* child */
	}
}

int main(int argc, char **argv)
{
	FILE * output = stdout;
	usb_dev_handle *handle = NULL;
	int opt;
	char *rrdb = NULL;
	int delay = 500;
	int scale = 1;
	int reset = 0;
	int voltage = 230;
	int background = 0;
	int i;

	usb_init();

	while ((opt = getopt(argc, argv, "bhRr:d:V:")) != -1) {
		switch (opt) {
		case 'h':
			usage(argv[0]);
			break;
		case 'r':
			rrdb = optarg;
			break;
		case 'R':
			reset = 1;
			break;
		case 'b':
			background = 1;
			break;
		case 'd':
			delay = strtol(optarg, NULL, 0);
			break;
		case 'V':
			voltage = strtol(optarg, NULL, 0);
			break;
		default:
			usage(argv[0]);
		}
	}

	if (optind < argc)
		scale = strtol(argv[optind++], NULL, 0);

	if (usbOpenDevice(&handle, 0, NULL, 0, PRODUCT, NULL, NULL, NULL) != 0) {
		fprintf(stderr, "error: could not find USB device \"%s\"\n", PRODUCT);
		exit(1);
	}

	if (reset) {
		send_reset(handle);
		return 0;
	}

	if (rrdb) {
		if (background)
			output = popen("rrdtool - > /dev/null 2>&1", "w");
		else
			output = popen("rrdtool -", "w");
		if (!output) {
			perror("popen");
			exit(1);
		}

		if (background)
			daemonize();

		for (;;) {
			get_power(handle);

			fprintf(output, "update %s N", rrdb);
			for (i = 0; i < NR_CHANNELS; i++) {
				fprintf(output, ":%d", hf.host_values[i] * voltage / NOMINAL_VOLTAGE / scale);
			}
			fprintf(output, "\n");

			fflush(output);
			usleep(delay * 1000);
		}
	} else {
		for (;;) {
			get_power(handle);

			for (i = 0; i < NR_CHANNELS; i++) {
				printf("%4d,", hf.host_values[i] * voltage / NOMINAL_VOLTAGE / scale);
			}
			printf("%4d,", hf.sample_count);
			printf("%02x", hf.gain_mask);
			printf("\n");

			fflush(stdout);
			usleep(delay * 1000);
		}
	}

	usb_close(handle);

	return 0;
}

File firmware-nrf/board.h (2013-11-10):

/* LEDs */
#define LED_A_PORT    PORTB
#define LED_A_DDR     DDRB
#define LED_A         PB0

#define led_a_on()     LED_A_PORT |=  _BV(LED_A);
#define led_a_off()    LED_A_PORT &= ~_BV(LED_A);
#define led_a_toggle() LED_A_PORT ^=  _BV(LED_A);

#define led_init() do {				\
		LED_A_DDR |= _BV(LED_A);	\
	} while (0);

/* SPI */
#define SPI_DDR  DDRA
#define SPI_PORT PORTA
#define SPI_PIN  PINA
#define SPI_SS   PA2
#define SPI_SCK  PA4
#define SPI_MISO PA5
#define SPI_MOSI PA6

/* Charger */
#define CHG_PORT	PORTA
#define CHG_PIN		PINA
#define CHG		PA7

#define chg_init()	do { CHG_PORT |= _BV(CHG); } while (0)
#define is_charging()	(!(PINA & _BV(PA7)))

/* nRF24L01+ SPI */
#define NRF_DDR  DDRA
#define NRF_PORT PORTA
#define NRF_CS   SPI_SS
#define NRF_CE   PA3

#define nrf_cs_h() (NRF_PORT |=  _BV(NRF_CS))
#define nrf_cs_l() (NRF_PORT &= ~_BV(NRF_CS))
#define nrf_ce_h() (NRF_PORT |=  _BV(NRF_CE))
#define nrf_ce_l() (NRF_PORT &= ~_BV(NRF_CE))

/* Analog */
#define ANALOG_PORT    PORTB
#define ANALOG_DDR     DDRB
#define ANALOG         PB1

#define analog_on()     ANALOG_PORT |=  _BV(ANALOG);
#define analog_off()    ANALOG_PORT &= ~_BV(ANALOG);

#define analog_init() do {			\
		ANALOG_DDR |= _BV(ANALOG);	\
	} while (0);

/* ADC */
#define ADC_COIL       (_BV(REFS1) | 0x01)
#define ADC_OFFSET_20X (_BV(REFS1) | 0x23)
#define ADC_COIL_1X    (_BV(REFS1) | 0x28)
#define ADC_COIL_20X   (_BV(REFS1) | 0x29)
#define ADC_VCC        (0x21)

#define AMP_TH 45 /* ~ 1024 / 20 */
#define ADC_VREF_mV (1100 / 4)
#define ADC_VREF_BITS (1024 / 4)

/* 4000W version */
#define CAL_POWER	4000
#define CAL_VOLTAGE	1121l
/* 6500W version */
//#define CAL_POWER	6500
//#define CAL_VOLTAGE	1060l
/* 12000W version */
//#define CAL_POWER	(12000 / 10)
//#define CAL_VOLTAGE	(1020l / 10)

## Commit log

2012-01-21 hardware: initial commit, rev0
    [usb-current-meter.brd, usb-current-meter.sch]
2012-01-23 hardware: add 8x schematic
    [usb-current-meter-8x.sch]
2012-01-23 hardware: first version with 1 module
    [usb-current-meter-8x.brd, usb-current-meter-8x.sch]
2012-01-23 hardware: progress save
    [usb-current-meter-8x.brd, usb-current-meter-8x.sch]
2012-01-24 hardware: add license, silkscreen
    [usb-current-meter.brd, usb-current-meter.sch]
2012-02-11 hardware: add some filtering capacitors
    [usb-current-meter.brd, usb-current-meter.sch]
2012-02-13 hardware: update variants, add notes
    [usb-current-meter.brd, usb-current-meter.sch]
2012-03-03 main: add reset_cpu request
    [main.c]
2012-03-24 firmware: initial current-meter firmware
2012-03-27 commandline: add control message error check
    [main.c]
2012-03-27 hardware: add calculations for 6.5kW full-scale
    [usb-current-meter.sch]
2012-03-28 firmware: power down analog pins digiatal logic
2012-03-28 hardware: 8x schematic updated
    [usb-current-meter-8x.brd, usb-current-meter-8x.sch]
2012-03-30 hardware: re-made calculations for 230V (welcome to 2012)
    [usb-current-meter.sch]
2012-03-30 firmware: use new scaler for 230V
2012-03-31 8x: progress save
    [usb-current-meter-8x.brd, usb-current-meter-8x.sch]
2012-03-31 firmware: adc: do not use ADC sleep mode
2012-03-31 firwmare: adc: remove now unused empty ADC isr
2012-03-31 commandline: add voltage scale option
2012-03-31 firmware: board.h: prepare macro for 6kW version
2012-03-31 firmware: adc: turn on bandgap during init
2012-03-31 firmware: rework arithmetic to get better precision
    [board.h, main.c]
2012-04-01 firmware: fix div_round macro
    [main.c]
2012-04-10 docs: add bc script used to get gain resistor values
2012-04-21 hardware: change values for use with 1.1Vref
    [usb-current-meter.brd, usb-current-meter.sch]
2012-06-14 8x: moved usb connector into the board
    [usb-current-meter-8x.brd]
2012-06-14 8x: remove old reference shapes
    [usb-current-meter-8x.brd]
2012-06-14 hw: move low-side connector .6mm out
    [usb-current-meter-8x.brd]
2012-06-14 hw: 8x: add silk
    [usb-current-meter-8x.brd, usb-current-meter-8x.sch]
2012-06-14 hw: add current-meter-nrf
    [current-meter-nrf.brd, current-meter-nrf.sch]
2012-06-14 hw: cosmetic refactor
    [current-meter-nrf.brd, current-meter-nrf.sch]
2012-06-14 hw: nrf: progress save
    [current-meter-nrf.brd, current-meter-nrf.sch]
2012-06-14 nrf: hw: progress save
    [current-meter-nrf.brd, current-meter-nrf.sch]
2012-07-24 hw: 8x: add part numbers
    [usb-current-meter-8x.brd, usb-current-meter-8x.sch]
2012-08-20 hw: nrf: add missing part value
    [current-meter-nrf.brd, current-meter-nrf.sch]
2012-08-22 fw: nrf: add adc support
2012-08-22 fw: nrf: add spi write optimized function
2012-08-31 fw-nrf: fix wrong adc channels
    [board.h]
2012-08-31 fw-nrf: use get_power, add debug print
2012-09-02 fw-nrf: add board id files
2012-09-08 hw: change opamp to lt2078
    [usb-current-meter.brd, usb-current-meter.sch]
2012-09-08 hw: add pdf schematics
2012-09-10 nw-nrf: change default fuses
2012-09-11 fw: adc: rise settle time to 70us
2012-09-15 hw: 8x: clean up schematics, add calcs
    [usb-current-meter-8x.sch]
2012-11-08 bl-8x: fix minor warning
    [main.c]
2012-11-10 fw-nrw: add charge detection
2012-11-19 hw: add note about series-cap
    [usb-current-meter.brd, usb-current-meter.sch]
2012-11-24 fw-nrf: jump directly to powerdown after tx
2012-11-25 hw: update hammond libs
    [current-meter-nrf.brd, current-meter-nrf.sch, usb-current-meter-8x.brd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]
2013-11-10 fw-nrf: change default sensor address

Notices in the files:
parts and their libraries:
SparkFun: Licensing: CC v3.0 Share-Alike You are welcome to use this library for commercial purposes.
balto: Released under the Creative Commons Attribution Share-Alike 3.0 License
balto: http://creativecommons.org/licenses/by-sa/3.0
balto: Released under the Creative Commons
